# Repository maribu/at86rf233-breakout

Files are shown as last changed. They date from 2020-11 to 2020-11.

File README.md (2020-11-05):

AT86RF233 Breakout
==================

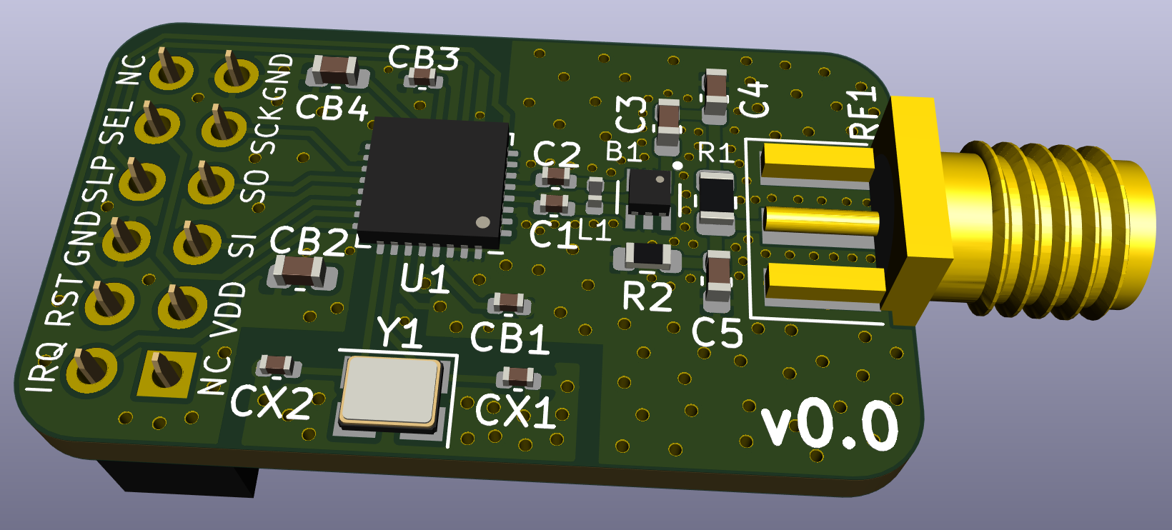
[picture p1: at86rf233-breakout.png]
Image of the AT86RF212B Breakout board


This Repository contains an AT86RF233 breakout board that uses the basic
application schematic given in Section 5.1 "Basic Application Schematic" on
page 15 of the AT86RF233 datasheet (07/2014), with two differences:

1. The optional clock output is omitted
2. The 2.4 gigahertz antenna circuit from the [AT86RF215-XPRO](https://static5.arrow.com/pdfs/2015/6/30/10/21/54/282/atm_/manual/251atreb215-xpro_design_documentation.pdf)
   is used instead the on given in the AT86RF233 basic application schematic.
   The shielding used in the AT86RF215-XPRO is omitted.

This board is intentionally pin compatible with the openlabs.co RPI 802.15.4
radio - but not based on their design.

WARNING
=======

1. It is highly recommended to not order PCBs based on this design as of now.
   This design has never been tested.
2. There is absolutely no warranty.
3. The AT86RF233 chip, the 2 x 6 female pin header, and the SMA connector are
   note included in the generated BOM an need to be hand soldered.

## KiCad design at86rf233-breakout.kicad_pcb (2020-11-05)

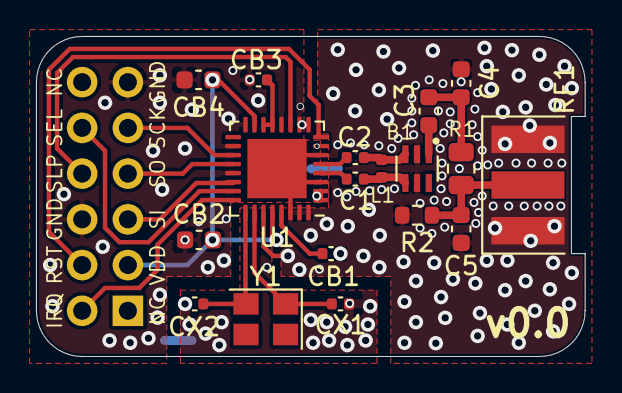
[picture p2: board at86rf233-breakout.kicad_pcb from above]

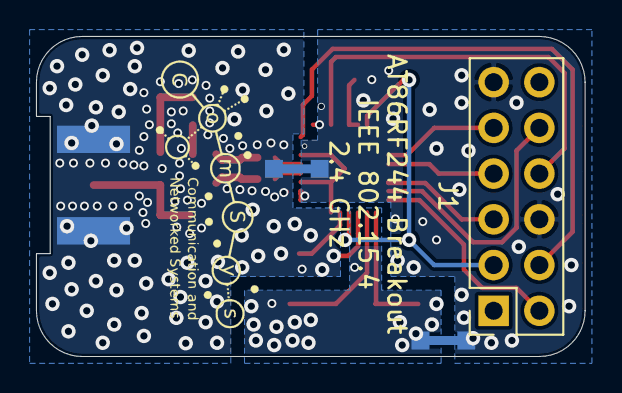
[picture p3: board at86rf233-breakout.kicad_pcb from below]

Board: 2 copper layers, 30.5 x 17.8 mm, 21 parts (3 on the bottom side), 22 nets.

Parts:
B1: Balun_HHM1711D1; TDK-HHM1711D1
C1, C2: 1.8 pF; C_0402_1005Metric
C3: 0.8 pF; C_0603_1608Metric
C4, C5: 1.2 pF; C_0603_1608Metric
CB1, CB3: 100 nF; C_0402_1005Metric
CB2, CB4: 1 µF; C_0603_1608Metric
CX1, CX2: 12 pF; C_0402_1005Metric
J1: RPi Header; PinSocket_2x06_P2.54mm_Vertical
L1: 5.6 nH; L_0402_1005Metric
R1: 0 Ω; R_0805_2012Metric
R2: 10 kΩ; R_0603_1608Metric
R3, R4: 0 Ω; R0
RF1: ANT; Connector-SMA
U1: AT86RF233-ZU; QFN-32-1EP_5x5mm_P0.5mm_EP3.3x3.3mm
Y1: 16 MHz; Crystal_SMD_TXC_7M-4Pin_3.2x2.5mm

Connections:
/ANT: C5.1, R1.2, R2.1, RF1.1
/ANT': C3.2, C4.1, R1.1
/ANT'': B1.1, C3.1
/AVDD: CB1.1, U1.29
/DVDD: CB3.1, U1.13, U1.14
/IRQ: J1.2, U1.24
/MISO: J1.7, U1.20
/MOSI: J1.5, U1.22
/RFN: C2.2, U1.5
/RFN': B1.3, C2.1, L1.2
/RFP: C1.2, U1.4
/RFP': B1.4, C1.1, L1.1
/RST: J1.4, U1.8
/SCLK: J1.9, U1.19
/SEL: J1.10, U1.23
/SLP_TR: J1.8, U1.11
/XTAL1: CX1.2, U1.26, Y1.1
/XTAL2: CX2.2, U1.25, Y1.2
GND: CB2.1, CB3.2, CB4.1, J1.6, J1.11, R3.2, R4.2, U1.1, U1.2, U1.7, U1.9, U1.10, U1.12, U1.16, U1.18, U1.21
GND2: CX1.1, CX2.1, R3.1
GNDA: B1.2, B1.5, C4.2, C5.2, CB1.2, R2.2, R4.1, RF1.2, U1.3, U1.6, U1.27, U1.30, U1.31, U1.32, U1.33
VDD: CB2.2, CB4.2, J1.3, U1.15, U1.28

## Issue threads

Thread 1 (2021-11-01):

Testing of first revision

henrikssn, 2021-11-01:
Did you ever end up testing this board?

maribu, 2021-11-01:
No, after testing the AT86RF215 breakout, we decided to just go with that. I do have some PCBs and the required parts to populate it lying around somewhere.

I will try to solder it soonish, if I manage to find the stuff and some spare time.
